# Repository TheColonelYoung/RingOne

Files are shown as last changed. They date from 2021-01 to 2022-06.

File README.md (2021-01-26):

# RingOne  
3D air mouse based on STM32  

Can be used for controlling CADs and every other manipulation in 3D space. Is based around STM32L452, IMU LSM6DSL (gyroscope and accelerometer) and Bluetooth low power module RN4871. Also contains battery management system for charging internal battery and also powering itself from this li-po battery (around 40 mah). Battery can be recharged via USB type C which can be also used for streaming data from accelerometer.  

Advanced USB capabilities are managed by STUSB1600 IC which communicate with host over CC lines. Button near bluettoth module serves as power up and also can be used to wake up device when is in power saving mode. For waking of device can be also used capability of accelerometer to detect taps. RGB LED diode is used to inform user about device status.  

During development, data can be saved to NOR Flash memory on board which is accessible via MCu CLI interface. Also connectors for SWD interface and debug UART are contained.  

## PCB  
 Front | Back |  
-------------------------|-------------------------|  
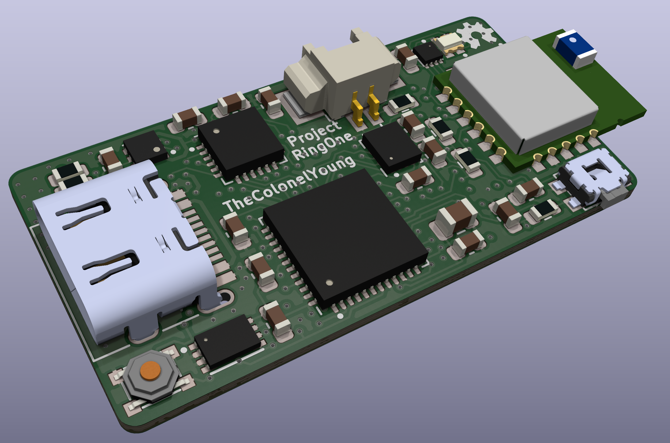
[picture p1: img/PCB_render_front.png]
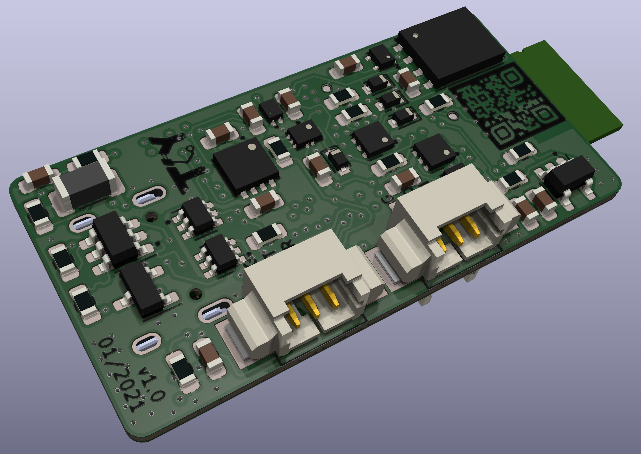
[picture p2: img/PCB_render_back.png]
 |   

Note: black silk screen on back side of PCB should be also white, back color of silkscreen is probably result of some bug in Kicad rendering engine

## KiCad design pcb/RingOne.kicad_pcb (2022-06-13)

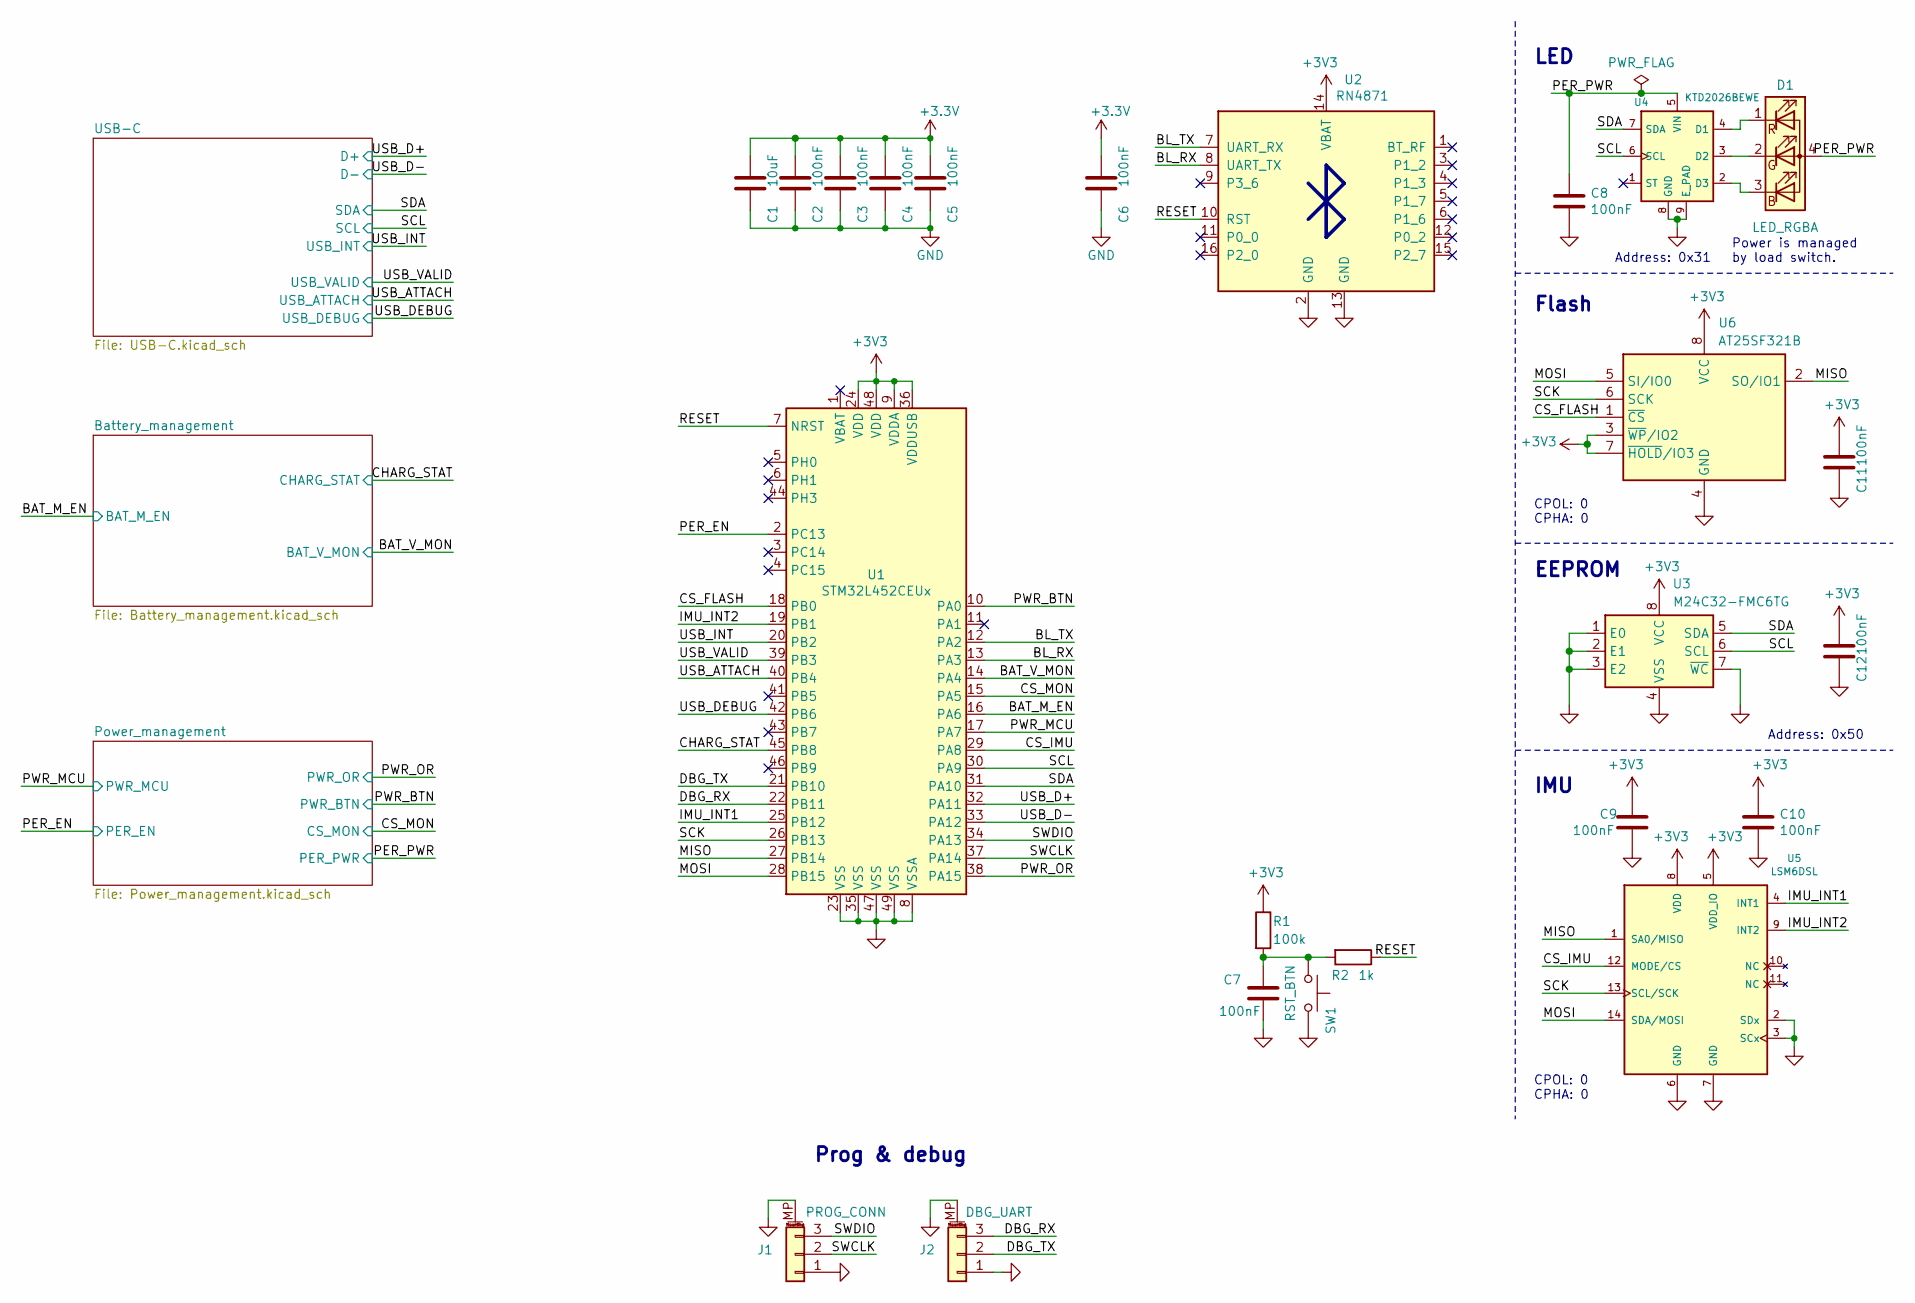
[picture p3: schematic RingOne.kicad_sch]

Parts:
C1: 10uF; C_0805_2012Metric
C2, C3, C4, C5, C6, C7, C8, C9, C10, C11, C12: 100nF; C_0603_1608Metric
D1: LED_RGBA; R_Array_Convex_2x0606
J1: PROG_CONN; Amphenol_10114830-11103LF_1x03_P1.25mm_Horizontal
J2: DBG_UART; Amphenol_10114830-11103LF_1x03_P1.25mm_Horizontal
R1: 100k; R_0603_1608Metric
R2: 1k; R_0603_1608Metric
SW1: RST_BTN; KMT031NGJLHS
U1: STM32L452CEUx; QFN-48-1EP_7x7mm_P0.5mm_EP5.6x5.6mm
U2: RN4871; Microchip_RN4871
U3: M24C32-FMC6TG; DFN-8-1EP_3x2mm_P0.5mm_EP1.3x1.5mm
U4: KTD2026BEWE; UTDFN-8-1EP_1.5x1.5mm_P0.4mm_EP0.8x1.45mm
U5: LSM6DSL; LGA-14_3x2.5mm_P0.5mm_LayoutBorder3x4y
U6: AT25SF321B; DFN-8-1EP_6x5mm_P1.27mm_EP4x4mm

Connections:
/BAT_M_EN: U1.16 (PA6); also elsewhere on the board
/BAT_V_MON: U1.14 (PA4); also elsewhere on the board
/BL_RX: U1.13 (PA3), U2.8 (UART_TX)
/BL_TX: U1.12 (PA2), U2.7 (UART_RX)
/CHARG_STAT: U1.45 (PB8); also elsewhere on the board
/CS_FLASH: U1.18 (PB0), U6.1 (~CS)
/CS_IMU: U1.29 (PA8), U5.12 (MODE/CS)
/CS_MON: U1.15 (PA5); also elsewhere on the board
/DBG_RX: J2.3, U1.22 (PB11)
/DBG_TX: J2.2, U1.21 (PB10)
/IMU_INT1: U1.25 (PB12), U5.4 (INT1)
/IMU_INT2: U1.19 (PB1), U5.9 (INT2)
/MISO: U1.27 (PB14), U5.1 (SA0/MISO), U6.2 (SO/IO1)
/MOSI: U1.28 (PB15), U5.14 (SDA/MOSI), U6.5 (SI/IO0)
/PER_EN: U1.2 (PC13); also elsewhere on the board
/PER_PWR: C8.1, D1.4 (A), U4.5 (VIN); also elsewhere on the board
/PWR_BTN: U1.10 (PA0); also elsewhere on the board
/PWR_MCU: U1.17 (PA7); also elsewhere on the board
/PWR_OR: U1.38 (PA15); also elsewhere on the board
/RESET: R2.1, U1.7 (NRST), U2.10 (RST)
/SCK: U1.26 (PB13), U5.13 (SCL/SCK), U6.6 (SCK)
/SCL: U1.30 (PA9), U3.6 (SCL), U4.6 (SCL); also elsewhere on the board
/SDA: U1.31 (PA10), U3.5 (SDA), U4.7 (SDA); also elsewhere on the board
/SWCLK: J1.2, U1.37 (PA14)
/SWDIO: J1.3, U1.34 (PA13)
/USB_ATTACH: U1.40 (PB4); also elsewhere on the board
/USB_D+: U1.32 (PA11); also elsewhere on the board
/USB_D-: U1.33 (PA12); also elsewhere on the board
/USB_DEBUG: U1.42 (PB6); also elsewhere on the board
/USB_INT: U1.20 (PB2); also elsewhere on the board
/USB_VALID: U1.39 (PB3); also elsewhere on the board
GND: C1.2, C2.2, C3.2, C4.2, C5.2, C6.2, C7.2, C8.2, C9.2, C10.2, C11.2, C12.2, J1.1, J1.MP (MountPin), J2.1, J2.MP (MountPin), SW1.2, U1.8 (VSSA), U1.23 (VSS), U1.35 (VSS), U1.47 (VSS), U1.49 (VSS), U2.2 (GND), U2.13 (GND), U3.1 (E0), U3.2 (E1), U3.3 (E2), U3.4 (VSS), U3.7 (~WC), U4.8 (GND), U4.9 (E_PAD), U5.2 (SDx), U5.3 (SCx), U5.6 (GND), U5.7 (GND), U6.4 (GND); also elsewhere on the board
unnamed: C7.1, R1.2, R2.2, SW1.1
unnamed: D1.1 (RK), U4.4 (D1)
unnamed: D1.2 (GK), U4.3 (D2)
unnamed: D1.3 (BK), U4.2 (D3)
no_connect_71: U1.1 (VBAT)
no_connect_72: U1.11 (PA1)
no_connect_73: U1.3 (PC14)
no_connect_74: U1.4 (PC15)
no_connect_75: U1.41 (PB5)
no_connect_76: U1.43 (PB7)
no_connect_77: U1.44 (PH3)
no_connect_78: U1.46 (PB9)
no_connect_79: U1.5 (PH0)
no_connect_80: U1.6 (PH1)
no_connect_81: U2.1 (BT_RF)
no_connect_82: U2.11 (P0_0)
no_connect_83: U2.12 (P0_2)
no_connect_84: U2.15 (P2_7)
no_connect_85: U2.16 (P2_0)
no_connect_86: U2.3 (P1_2)
no_connect_87: U2.4 (P1_3)
no_connect_88: U2.5 (P1_7)
no_connect_89: U2.6 (P1_6)
no_connect_90: U2.9 (P3_6)
no_connect_91: U4.1 (ST)
no_connect_95: U5.10 (NC)
no_connect_96: U5.11 (NC)

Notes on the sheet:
IMU
LED
CPOL: 0 CPHA: 0
Address: 0x50
EEPROM
Address: 0x31
Power is managed by load switch.
Flash
Prog & debug

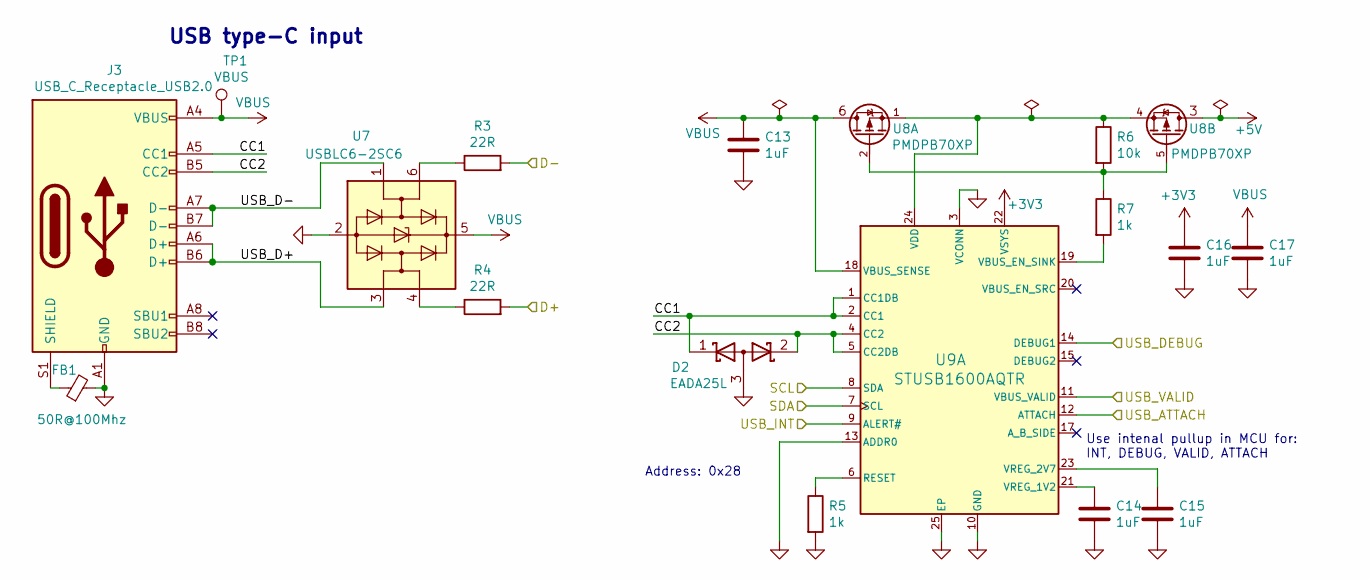
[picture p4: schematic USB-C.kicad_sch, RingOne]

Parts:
C13, C14, C15, C16, C17: 1uF; C_0603_1608Metric
D2: EADA25L; SOT-23
FB1: 50R@100Mhz; L_1206_3216Metric
J3: USB_C_Receptacle_USB2.0; USB_C_Receptacle_HRO_TYPE-C-31-M-12
R3, R4: 22R; R_0603_1608Metric
R5, R7: 1k; R_0603_1608Metric
R6: 10k; R_0603_1608Metric
TP1: VBUS; TestPoint_Pad_D0.5mm
U7: USBLC6-2SC6; SOT-23-6
U8: PMDPB70XP; UDFN-6-2EP_2x2mm_P0.65mm_EP1x0.7mm
U9: STUSB1600AQTR; QFN-24-1EP_4x4mm_P0.5mm_EP2.7x2.7mm

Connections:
+5V: U8.3, U8.8; also elsewhere on the board
/SCL: U9.8 (SDA); also elsewhere on the board
/SDA: U9.7 (SCL); also elsewhere on the board
/USB-C/CC1: D2.1 (K), J3.A5 (CC1), U9.1 (CC1DB), U9.2 (CC1)
/USB-C/CC2: D2.2 (K), J3.B5 (CC2), U9.4 (CC2), U9.5 (CC2DB)
/USB-C/USB_D+: J3.A6 (D+), J3.B6 (D+), U7.3 (I/O2)
/USB-C/USB_D-: J3.A7 (D-), J3.B7 (D-), U7.1 (I/O1)
/USB_ATTACH: U9.12 (ATTACH); also elsewhere on the board
/USB_D+: R4.2; also elsewhere on the board
/USB_D-: R3.2; also elsewhere on the board
/USB_DEBUG: U9.14 (DEBUG1); also elsewhere on the board
/USB_INT: U9.9 (ALERT#); also elsewhere on the board
/USB_VALID: U9.11 (VBUS_VALID); also elsewhere on the board
GND: C13.2, C14.2, C15.2, C16.2, C17.2, D2.3 (A), FB1.2, J3.A1 (GND), J3.A12 (GND), J3.B1 (GND), J3.B12 (GND), R5.2, U7.2 (GND), U9.3 (VCONN), U9.10 (GND), U9.13 (ADDR0), U9.25 (EP); also elsewhere on the board
unnamed: C14.1, U9.21 (VREG_1V2)
unnamed: C15.1, U9.23 (VREG_2V7)
unnamed: FB1.1, J3.S1 (SHIELD)
unnamed: R3.1, U7.6 (I/O1)
unnamed: R4.1, U7.4 (I/O2)
unnamed: R5.1, U9.6 (RESET)
unnamed: R6.1, U8.1, U8.4, U9.24 (VDD)
unnamed: R6.2, R7.1, U8.2, U8.5
unnamed: R7.2, U9.19 (VBUS_EN_SINK)
VBUS: C13.1, C17.1, J3.A4 (VBUS), J3.A9 (VBUS), J3.B4 (VBUS), J3.B9 (VBUS), TP1.1, U7.5 (VBUS), U8.6, U8.7, U9.18 (VBUS_SENSE)
no_connect_69: J3.A8 (SBU1)
no_connect_70: J3.B8 (SBU2)
no_connect_92: U9.15 (DEBUG2)
no_connect_93: U9.17 (A_B_SIDE)
no_connect_94: U9.20 (VBUS_EN_SRC)

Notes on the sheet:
Address: 0x28
USB type-C input
Use intenal pullup in MCU for: INT, DEBUG, VALID, ATTACH

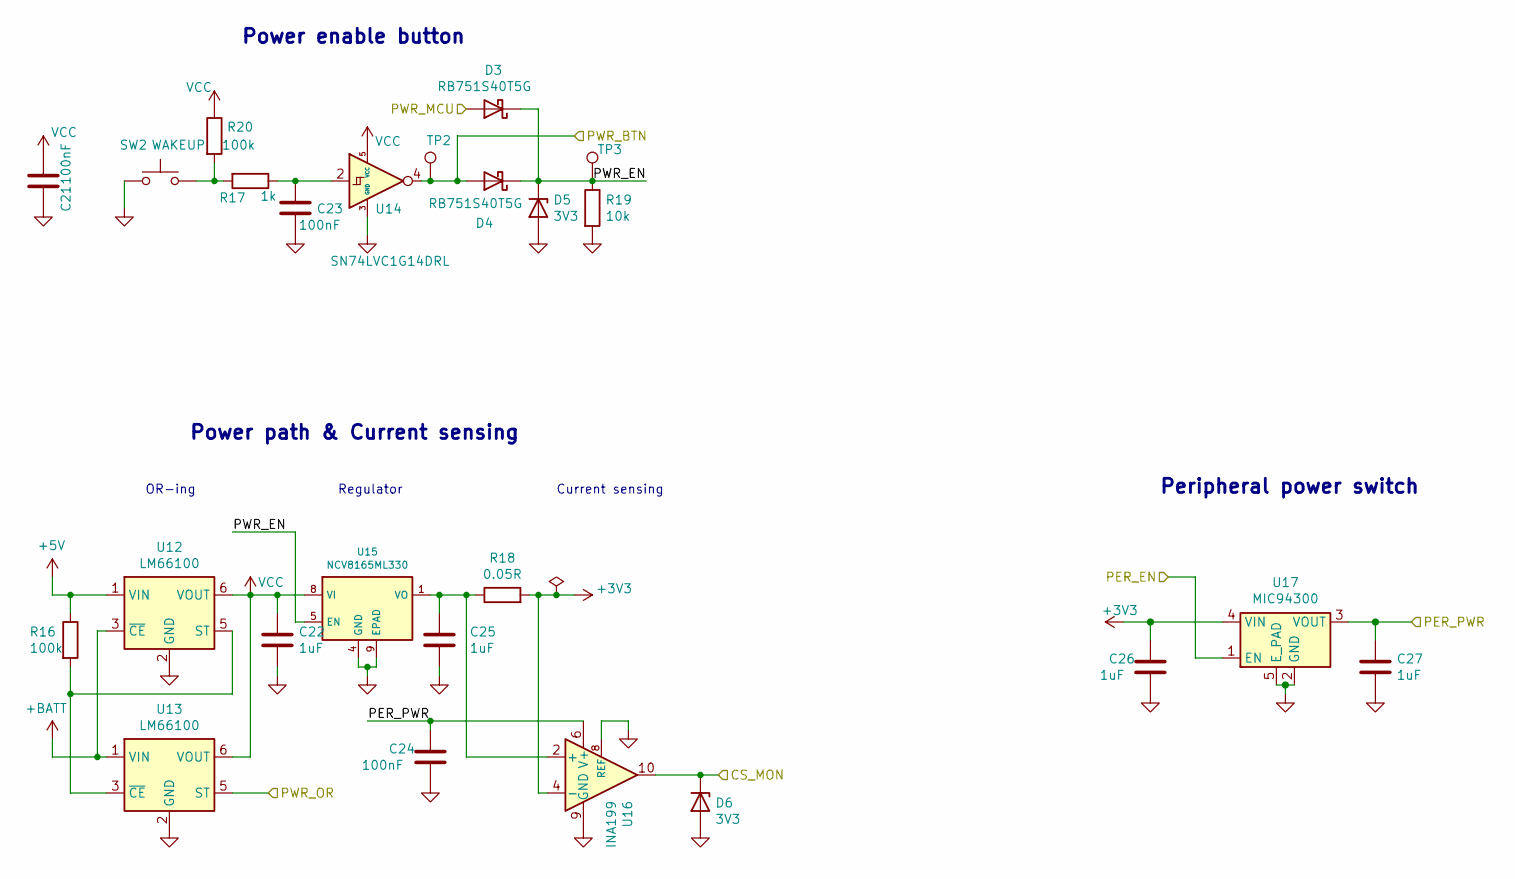
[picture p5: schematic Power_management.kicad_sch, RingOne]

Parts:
C21, C23, C24: 100nF; C_0603_1608Metric
C22, C25, C26, C27: 1uF; C_0603_1608Metric
D3, D4: RB751S40T5G; D_SOD-523
D5, D6: 3V3; D_SOD-523
R16, R20: 100k; R_0603_1608Metric
R17: 1k; R_0603_1608Metric
R18: 0.05R; R_0603_1608Metric
R19: 10k; R_0603_1608Metric
SW2: WAKEUP; EVQ-P7J01P
TP2, TP3: TestPoint; TestPoint_Pad_D0.5mm
U12, U13: LM66100; SOT-363_SC-70-6
U14: SN74LVC1G14DRL; SOT-553
U15: NCV8165ML330; DFN-8-1EP_3x3mm_P0.65mm_EP1.55x2.4mm
U16: INA199; UQFN-10_1.4x1.8mm_P0.4mm
U17: MIC94300; MLF-4_1.2x1.6mm_P0.5_1EP_0.85x0.5mm

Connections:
+5V: R16.1, U12.1 (VIN); also elsewhere on the board
+BATT: U12.3 (~CE), U13.1 (VIN); also elsewhere on the board
/CS_MON: D6.1 (K), U16.10; also elsewhere on the board
/PER_EN: U17.1 (EN); also elsewhere on the board
/PER_PWR: C24.1, C27.1, U16.6 (V+), U17.3 (VOUT); also elsewhere on the board
/PWR_BTN: D4.2 (A), TP2.1, U14.4; also elsewhere on the board
/PWR_MCU: D3.2 (A); also elsewhere on the board
/PWR_OR: U13.5 (ST); also elsewhere on the board
/Power_management/PWR_EN: D3.1 (K), D4.1 (K), D5.1 (K), R19.1, TP3.1, U15.5 (EN)
GND: C21.2, C22.2, C23.2, C24.2, C25.2, C26.2, C27.2, D5.2 (A), D6.2 (A), R19.2, SW2.1, U12.2 (GND), U13.2 (GND), U14.3 (GND), U15.4 (GND), U15.9 (EPAD), U16.8 (REF), U16.9 (GND), U17.2 (GND), U17.5 (E_PAD); also elsewhere on the board
unnamed: C23.1, R17.1, U14.2
unnamed: C25.1, R18.1, U15.1 (VO), U16.2 (+), U16.3 (+)
unnamed: R16.2, U12.5 (ST), U13.3 (~CE)
unnamed: R17.2, R20.2, SW2.2
VCC: C21.1, C22.1, R20.1, U12.6 (VOUT), U13.6 (VOUT), U14.5 (VCC), U15.8 (VI)
no_connect_98: U14.1 (NC)

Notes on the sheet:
Regulator
Power path & Current sensing
Current sensing
Power enable button
Peripheral power switch
OR-ing

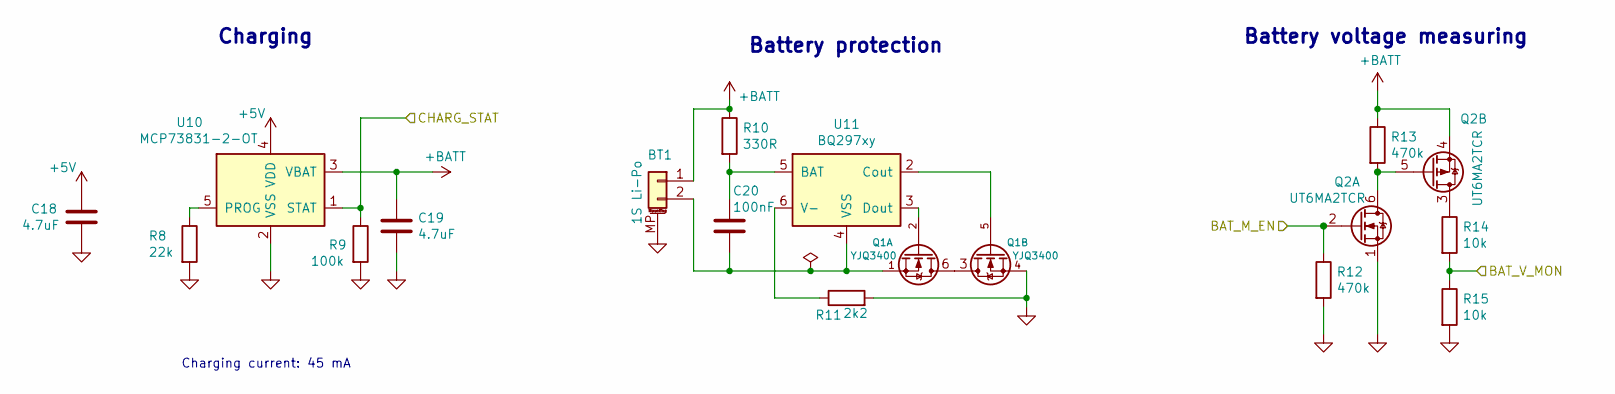
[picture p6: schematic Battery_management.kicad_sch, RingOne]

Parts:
BT1: 1S Li-Po; Amphenol_10114830-11102LF_1x02_P1.25mm_Horizontal
C18, C19: 4.7uF; C_0603_1608Metric
C20: 100nF; C_0603_1608Metric
Q1: YJQ3400; UDFN-6-2EP_2x2mm_P0.65mm_EP1x0.7mm
Q2: UT6MA2TCR; UDFN-6-2EP_2x2mm_P0.65mm_EP1x0.7mm
R8: 22k; R_0603_1608Metric
R9: 100k; R_0603_1608Metric
R10: 330R; R_0603_1608Metric
R11: 2k2; R_0603_1608Metric
R12, R13: 470k; R_0603_1608Metric
R14, R15: 10k; R_0603_1608Metric
U10: MCP73831-2-OT; SOT-23-5
U11: BQ297xy; WSON-6_1.5x1.5mm_P0.5mm

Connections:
+5V: C18.1, U10.4 (VDD); also elsewhere on the board
+BATT: BT1.1, C19.1, Q2.4 (SP), Q2.8 (SP), R10.1, R13.1, U10.3 (VBAT); also elsewhere on the board
/BAT_M_EN: Q2.2 (GN), R12.1; also elsewhere on the board
/BAT_V_MON: R14.2, R15.1; also elsewhere on the board
/CHARG_STAT: R9.1, U10.1 (STAT); also elsewhere on the board
GND: BT1.MP (MountPin), C18.2, C19.2, Q1.4 (S2), Q2.1 (SN), R8.2, R9.2, R11.2, R12.2, R15.2, U10.2 (VSS); also elsewhere on the board
unnamed: C20.1, R10.2, U11.5 (BAT)
unnamed: BT1.2, C20.2, Q1.1 (S), U11.4 (VSS)
unnamed: Q1.2 (G1), U11.3 (Dout)
unnamed: Q1.3 (D2), Q1.6 (D2), Q1.7 (D2), Q1.8 (D2)
unnamed: Q1.5 (G2), U11.2 (Cout)
unnamed: Q2.3 (DP), R14.1
unnamed: Q2.5 (GP), Q2.6 (DN), Q2.7 (DN), R13.2
unnamed: R8.1, U10.5 (PROG)
unnamed: R11.1, U11.6 (V-)
no_connect_97: U11.1 (NC)

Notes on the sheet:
Charging
Charging current: 45 mA
Battery voltage measuring
Battery protection

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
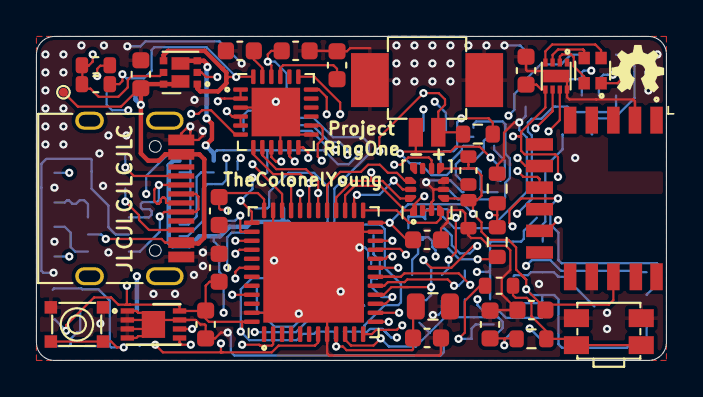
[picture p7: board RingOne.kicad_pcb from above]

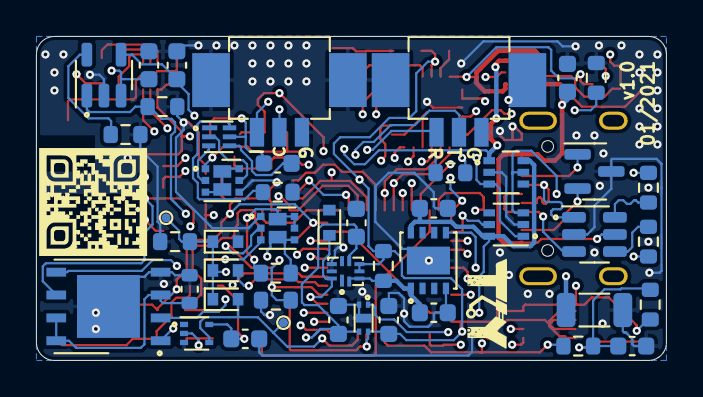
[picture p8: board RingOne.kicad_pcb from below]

Board: 4 copper layers, 35.0 x 18.0 mm, 82 parts (47 on the bottom side), 68 nets.

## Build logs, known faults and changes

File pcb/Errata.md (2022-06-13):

# Errata

## V1.0
- USB data lines are swapped
    - Consequences: USB communication is not working
    - Solution: remove 22R resistors on data lines and connect wires to resistors pads to reconnect lines properly

- Power switch detection have wrong voltage level
    - GPIO are 5V tolerant only when VDD is applied
    - Because switch is used to enable MCU power there is short interval when voltage higher then 3.6V is applied to GPIO
    - Consequences: There is possibility that MCU can be damaged during power enabling sequence
    - Solution: add 100k resistor to PWR_BTN connection, trace can be cut near PWR_BTN test point and is enough space to solder resistor to traces

- Zener diode on PWR_EN net have incorrect rating
    - Voltage produced by Schmitt trigger is equal to VCC (USB VCC - up to 5V), zener diode has rating of 3.3V
    - Zener diode will be open after power is enabled by power switch
    - Consequences: Zener diode damage, possible damage of Schmitt trigger

- Switched SCL a SDA lines to USB controller
    - Consequences: MCU cannot communicate with STUSB1600
    - Solution: cut and rewire traces 

- Layout of LED diode is incorrect
    - Consequences: Diode will not light up
    - Solution: turn diode by 90°, soldering will not be easy but is possible

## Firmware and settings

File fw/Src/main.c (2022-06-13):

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
/* Includes ------------------------------------------------------------------*/
#include "main.h"
#include "usb_device.h"

/* USER CODE BEGIN Includes */
#include "device/device.hpp"
#include "tools/tasker.hpp"
#include "apps/i2c_scanner.hpp"
#include "led/KTD2026.hpp"
#include "misc/text_transform.hpp"
/* USER CODE END Includes */

ADC_HandleTypeDef hadc1;

I2C_HandleTypeDef hi2c1;

IWDG_HandleTypeDef hiwdg;

UART_HandleTypeDef hlpuart1;
UART_HandleTypeDef huart3;

SPI_HandleTypeDef hspi2;

TIM_HandleTypeDef htim2;

void SystemClock_Config(void);
static void MX_GPIO_Init(void);
static void MX_ADC1_Init(void);
static void MX_I2C1_Init(void);
static void MX_LPUART1_UART_Init(void);
static void MX_USART3_UART_Init(void);
static void MX_SPI2_Init(void);
static void MX_TIM2_Init(void);
static void MX_IWDG_Init(void);
/**
  * @brief  The application entry point.
  * @retval int
  */
int main(void)
{
  /* MCU Configuration--------------------------------------------------------*/

  /* Reset of all peripherals, Initializes the Flash interface and the Systick. */
  HAL_Init();

  /* Configure the system clock */
  SystemClock_Config();

  /* Initialize all configured peripherals */
  MX_GPIO_Init();
  MX_ADC1_Init();
  MX_I2C1_Init();
  MX_LPUART1_UART_Init();
  MX_USART3_UART_Init();
  MX_SPI2_Init();
  MX_USB_DEVICE_Init();
  MX_TIM2_Init();
  MX_IWDG_Init();
  /* USER CODE BEGIN 2 */

    HAL_Delay(1);

    device()->Enable_CLI(device()->mcu->USB_port);
    device()->Enable_Filesystem();
    device()->cli->Enable_filesystem_executable(device()->fs);

    device()->mcu->I_WDG->Start(Independent_watchdog::Prescaler::_256, Independent_watchdog::Calculate_register(4000,Independent_watchdog::Prescaler::_256 ));

    Tasker::Instance(device()->mcu->TIM_2);
    Tasker::Instance()->New_event(500000, -1, device()->mcu->I_WDG, &Independent_watchdog::Reload, 0, "Watchdog");

    auto peripheral_enable = new Pin('C',13);
    peripheral_enable->Set(true);

    auto app = new I2C_scanner(device()->mcu->I2C_1);

    // LED
    auto led = new KTD2026(*(device()->mcu->I2C_1), 0b01100010);
    led->Test();

    // IMU
    uint8_t tx[2] = {0x8f, 0x00};
    uint8_t rx[2] = {0xff, 0xff};
    HAL_SPI_TransmitReceive (&hspi2, tx, rx, 2, 5000);
    device()->cli->Print("0x" + dec2hex(rx[1]));

    // Bluetooth module
    HAL_Delay(10);
    uint8_t CMD_mode[5] = "$$$";
    HAL_UART_Transmit(&hlpuart1,(uint8_t*)CMD_mode, 3, 5000);
    HAL_Delay(10);
    uint8_t echo_mode[3] = "+\r";
    HAL_UART_Transmit(&hlpuart1,(uint8_t*)echo_mode, 2, 5000);

  /* USER CODE END 2 */

  /* Infinite loop */
  /* USER CODE BEGIN WHILE */
    while (1) {
    /* USER CODE END WHILE */

    /* USER CODE BEGIN 3 */
    }
  /* USER CODE END 3 */
}

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


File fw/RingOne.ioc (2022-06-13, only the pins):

Mcu.UserName=STM32L452CEUx
PA0.GPIO_Label=PWR_BTN
PA0.Signal=SYS_WKUP1
PA10.Signal=I2C1_SDA
PA11.Signal=USB_DM
PA12.Signal=USB_DP
PA2.GPIO_Label=BL_TX_LP
PA2.Signal=LPUART1_TX
PA3.GPIO_Label=BL_RX_LP
PA3.Signal=LPUART1_RX
PA4.GPIO_Label=BAT_V_MON
PA4.Signal=ADCx_IN9
PA5.GPIO_Label=CS_MON
PA5.Signal=ADCx_IN10
PA6.GPIO_Label=BAT_M_EN
PA6.Signal=GPIO_Output
PA7.GPIO_Label=PWR_MCU
PA7.Signal=GPIO_Output
PA8.GPIO_Label=CS_IMU
PA8.Signal=GPIO_Output
PA9.Signal=I2C1_SCL
PB0.GPIO_Label=CS_FLASH
PB0.Signal=GPXTI0
PB1.GPIO_Label=IMU_INT2
PB1.Signal=GPXTI1
PB10.GPIO_Label=DBG_TX
PB10.Signal=USART3_TX
PB11.GPIO_Label=DBG_RX
PB11.Signal=USART3_RX
PB12.GPIO_Label=IMU_INT1
PB12.Signal=GPIO_Output
PB13.Signal=SPI2_SCK
PB14.Signal=SPI2_MISO
PB15.Signal=SPI2_MOSI
PB2.GPIO_Label=USB_INT
PB2.Signal=GPXTI2
PB6.GPIO_Label=USB_DEBUG
PB6.Signal=GPIO_Input
PB8.GPIO_Label=CHARG_STAT
PB8.Signal=GPIO_Input
PC13.GPIO_Label=PER_EN
PC13.Signal=GPIO_Output

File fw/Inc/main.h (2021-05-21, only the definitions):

#define PER_EN_Pin GPIO_PIN_13
#define PER_EN_GPIO_Port GPIOC
#define PWR_BTN_Pin GPIO_PIN_0
#define PWR_BTN_GPIO_Port GPIOA
#define BL_TX_LP_Pin GPIO_PIN_2
#define BL_TX_LP_GPIO_Port GPIOA
#define BL_RX_LP_Pin GPIO_PIN_3
#define BL_RX_LP_GPIO_Port GPIOA
#define BAT_V_MON_Pin GPIO_PIN_4
#define BAT_V_MON_GPIO_Port GPIOA
#define CS_MON_Pin GPIO_PIN_5
#define CS_MON_GPIO_Port GPIOA
#define BAT_M_EN_Pin GPIO_PIN_6
#define BAT_M_EN_GPIO_Port GPIOA
#define PWR_MCU_Pin GPIO_PIN_7
#define PWR_MCU_GPIO_Port GPIOA
#define CS_FLASH_Pin GPIO_PIN_0
#define CS_FLASH_GPIO_Port GPIOB
#define IMU_INT2_Pin GPIO_PIN_1
#define IMU_INT2_GPIO_Port GPIOB
#define USB_INT_Pin GPIO_PIN_2
#define USB_INT_GPIO_Port GPIOB
#define DBG_TX_Pin GPIO_PIN_10
#define DBG_TX_GPIO_Port GPIOB
#define DBG_RX_Pin GPIO_PIN_11
#define DBG_RX_GPIO_Port GPIOB
#define IMU_INT1_Pin GPIO_PIN_12
#define IMU_INT1_GPIO_Port GPIOB
#define CS_IMU_Pin GPIO_PIN_8
#define CS_IMU_GPIO_Port GPIOA
#define SWDIO_Pin GPIO_PIN_13
#define SWDIO_GPIO_Port GPIOA
#define SWCLK_Pin GPIO_PIN_14
#define SWCLK_GPIO_Port GPIOA
#define PWR_OR_Pin GPIO_PIN_15
#define PWR_OR_GPIO_Port GPIOA
#define USB_VALID_Pin GPIO_PIN_3
#define USB_VALID_GPIO_Port GPIOB
#define USB_ATTACH_Pin GPIO_PIN_4
#define USB_ATTACH_GPIO_Port GPIOB
#define USB_DEBUG_Pin GPIO_PIN_6
#define USB_DEBUG_GPIO_Port GPIOB
#define CHARG_STAT_Pin GPIO_PIN_8
#define CHARG_STAT_GPIO_Port GPIOB

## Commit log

2021-01-18 KiCAD project initialization
    [RingOne.kicad_pcb, RingOne.kicad_sch]
2021-01-20 KiCAD: update library paths
2021-01-20 Schema: initial placing of components
    [RingOne.kicad_sch]
2021-01-21 Schema: add power path control, input button and bluetooth module
    [BTN_Denoise.kicad_sch, RingOne.kicad_sch]
2021-01-23 Schema: finalization of schematic, break main page into hierarchical
    [BTN_Denoise.kicad_sch, Battery_management.kicad_sch, Power_management.kicad_sch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]
2021-01-23 PCB: routing of all components
    [RingOne.kicad_pcb]
2021-01-23 CubeMX initialization, MCU pin function assignment
2021-01-25 PCB & Schema: update page layout
    [RingOne.kicad_pcb]
2021-01-28 Schema & PCB: add pull up to wakeup button
    [Power_management.kicad_sch, RingOne.kicad_pcb, RingOne.kicad_sch]
2021-02-01 PCB: add connection of connector mounting point to ground
    [Battery_management.kicad_sch, Power_management.kicad_sch, RingOne.kicad_pcb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]
2021-06-09 project: add I2C scanner app and peripheral powerup
2022-06-13 FW: add testing of connection with LED driver, IMU and Bluetooth module
2022-06-13 Schema & PCB: Update page layout, add notes about SPI modes and I2C addresses
    [Battery_management.kicad_sch, Power_management.kicad_sch, RingOne.kicad_pcb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]
2022-06-13 Errata: add section about STUSB1600 and LED PCB layout

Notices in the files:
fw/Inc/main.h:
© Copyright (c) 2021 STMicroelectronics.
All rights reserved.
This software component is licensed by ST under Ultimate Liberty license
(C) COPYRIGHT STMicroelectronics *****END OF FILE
